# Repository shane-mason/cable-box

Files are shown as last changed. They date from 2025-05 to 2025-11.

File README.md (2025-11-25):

# cable-box
3d Printable Cable Box Model

The models were used to make a 3-d printed cable box replica to house a Raspberry Pi 5 for a cable simulation built using FieldStation42.

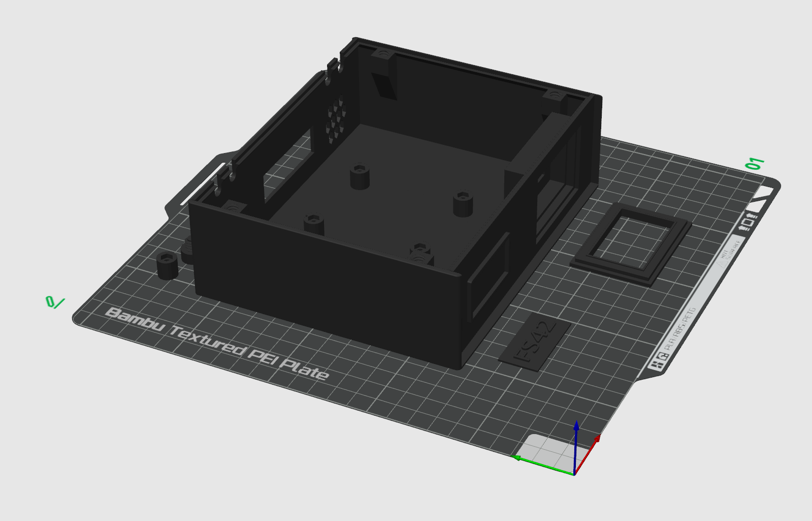
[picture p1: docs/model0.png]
A screenshot cable box model


To use the models, clone the repository and print both sets:

```
CableBox-main.stl - Contains the main box, trim pieces and foot screws.
CableBox-bottom.stl - Conains the bottom of the box.
```

## List of Materials Used
* [3x4 Matrix Keypad](https://www.adafruit.com/product/3845)
* [4 Digit 7 Segment TM1637 LED Display Board](https://www.amazon.com/dp/B0BFQNFX6D)
* [Raspberry Pi 5 - with active cooler](https://www.adafruit.com/product/5815)
* [F2F Jumper Wires](https://www.adafruit.com/product/1950)
* 6"+ Micro HDMI to HDMI Adapter (pigtail)
* Plexiglass (1/8th inch)
* 4 M2.5 screws and nuts
* 4 M2 screws and nuts
* Superglue

## Building the Box
The put it all together, follow the steps below. At the finish, you should have a box that looks like this:
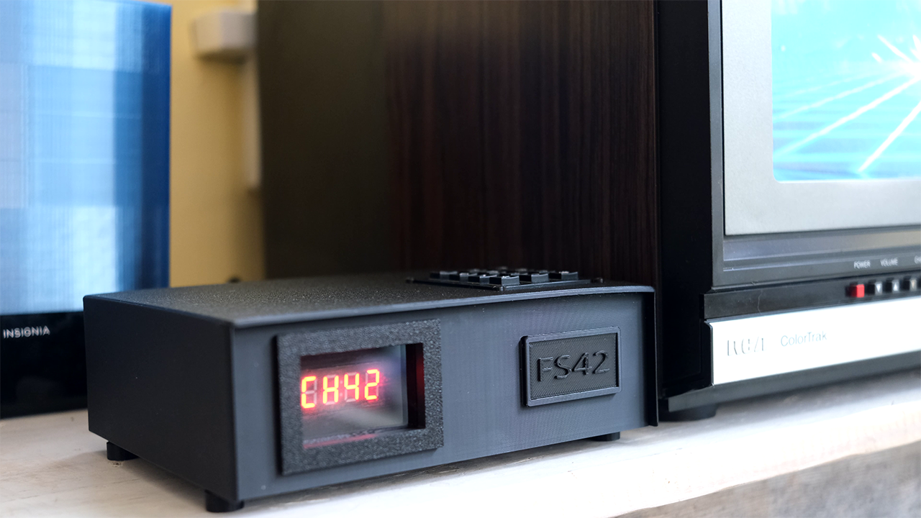
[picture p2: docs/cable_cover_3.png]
A cable box on a table with wired connecting components


### Step 1 - Printing
Print both models above. I used PLA with a .4 mm nozel on a textured plate - but ABS should work.

### Step 2 - Mounting the Pi
The printed model contains mounts for the raspberry pi 5 on the top of the box. There are cutouts in each mounting post for an M2.5 nut to fit into - secure it with superglue.
        
After the superglue is dried, just use M2.5 screws to secure it to the post.

Its important to use a pi with an active cooler - otherwise it will likely heat up and throttle perfomance. 

### Step 3 - Mount the Keypad
The keypad mounts using M2 screws and nuts in the corners of the cutout on the top of the box.

### Step 4 - Mount the LED Display
The display mounts in the cutout in the front of the box using superglue. The fit should be fairly tight, but it also works as long as it is glued to one of the two sides. There is room for improvement in this part of the design for sure.

Optional: cut plexiglass to SIZE and fit in front of the display.

Fit black trim piece over the display area.

### Step 5 Wire It Up!
In this step, you'll connect all the wires. Your setup should look like the picture below at the end of this step:

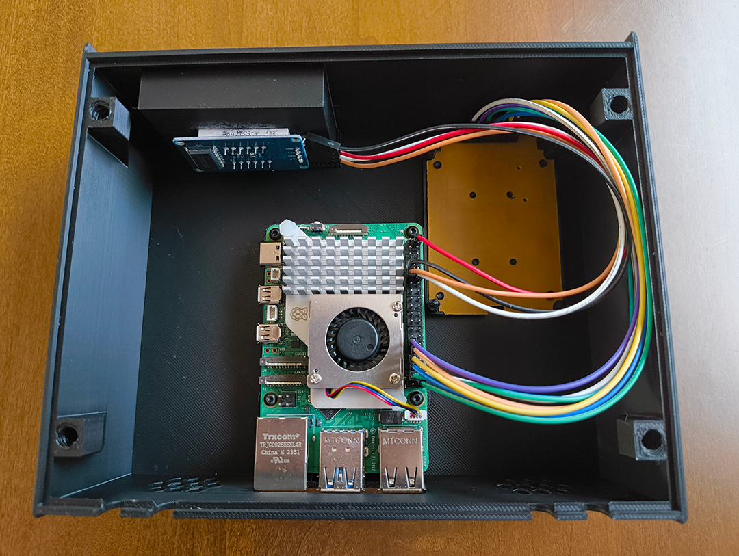
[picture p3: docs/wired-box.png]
A cable box on a table with wired connecting components


#### TM1637 LED Display Board

The following table shows the connections betwen the Rasberry Pi 5 and the TM1637 LED Display Board.

| Raspberry PI  |LED Display |
| --- | --- |
|A 5v |VCC |
|GND  |GND |
|GPIO17  |CLK |
|GPIO18  | DIO |

#### 3x4 Matrix Keypad

The following table shows the connections between the Raspberry Pi 5 and the 3x4 Matrix Keypad. For more information on the pinouts for this keypad and the Raspberry Pi 5, see [this Adafruit Learning Guide](https://learn.adafruit.com/matrix-keypad/overview).

| Raspberry PI  |Keypad |
| --- | --- |
|GPIO20|C2|
|GPIO05|R1|
|GPIO26|C1|
|GPIO19|R4|
|GPIO21|C3|
|GPIO13|R3|
|GPIO06|R2|

#### Fritzing Diagram

The following diagram shows an overview of the connections.

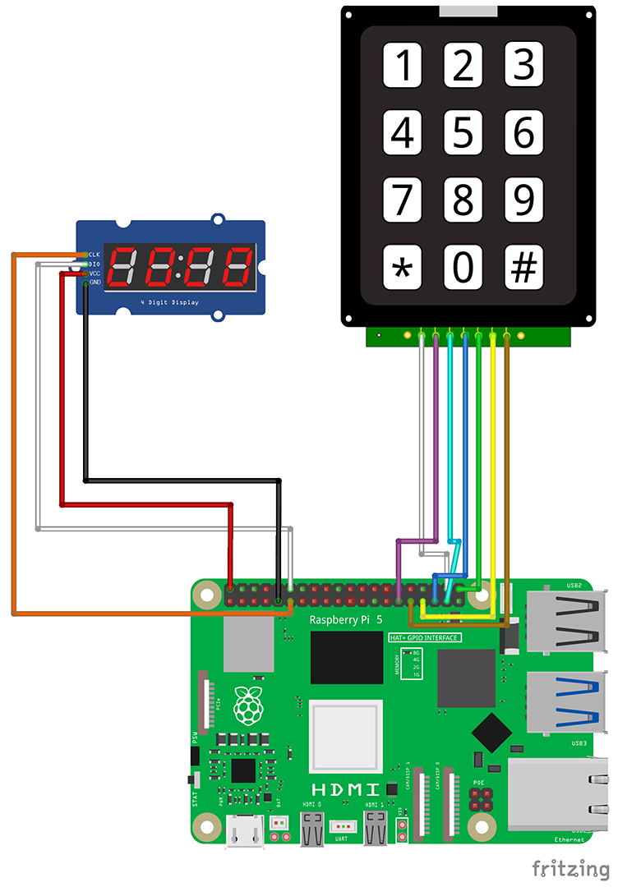
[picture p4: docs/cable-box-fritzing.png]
A connection diagram


Additional documentation with images is in-progress.

### Step 5: Connect Power & HDMI

In this step, just connect the micro-HDMI to HDMI pigtail to the Pi's micro-HDMI output and the power cable to the Pi's USB C connector and run them through the openings on the side closest to the connectors. You will probably want to use use something to prevent the cables from being pulled, so I use some thick copper wire. A think ziptie or some tape wil work also. When this step is completed, it should look like the picture below.

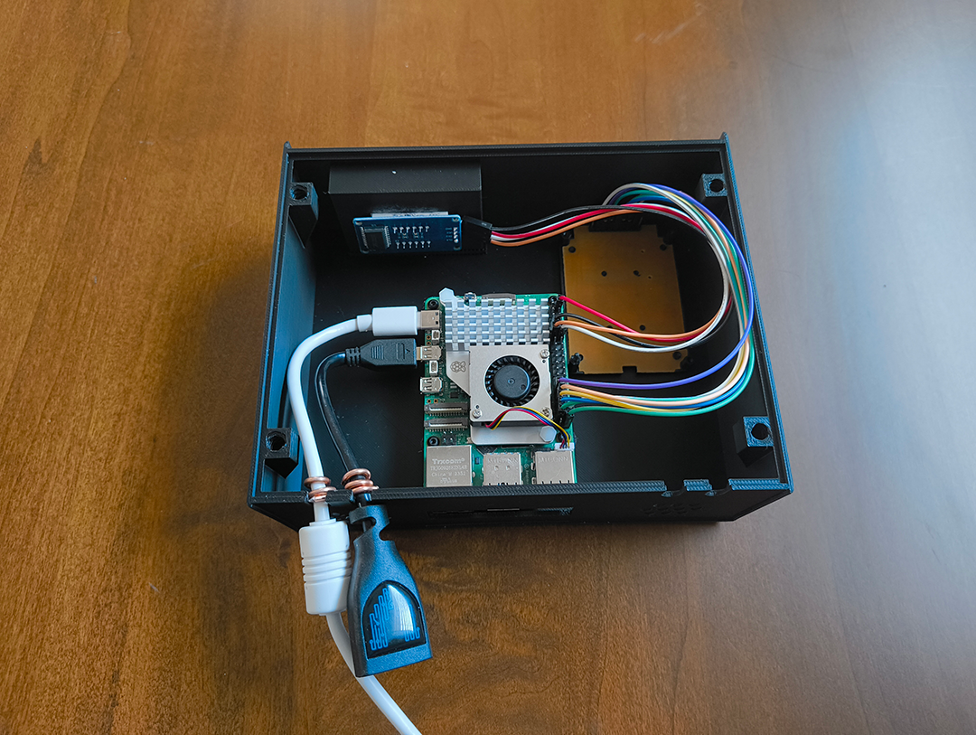
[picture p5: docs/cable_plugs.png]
Cable box with wires


### Step 6: Secure Bottom
Use the foot screws in the first print to secure the bottom piece from the second print.

## Setting Up the Software

To use the cable box script, you will need to install the python drivers for the LED display and matrix keypad. The script is located in the FieldStation42 repo at `fs42/pi/cable_box.py` ([link](https://github.com/shane-mason/FieldStation42/blob/main/fs42/pi/cable_box.py)).

### Install Keypad Drivers

For the matrix keypad, you you first need to install Adafruit Blinka libraries. 
- [Follow this guide to install CircuitPython via Blinka](https://learn.adafruit.com/circuitpython-on-raspberrypi-linux/installing-circuitpython-on-raspberry-pi)

Next, install the matrix keypad driver using pip3 (after you activate your virtual env)

```
source env/bin/activate
pip3 install adafruit-circuitpython-matrixkeypad
```

### Install LED Drivers

Use pip to install tm1637 LED drivers

```
source env/bin/activate
pip3 install raspberrypi-tm1637
```

### 

If you get an error along the lines of:
```
RuntimeError: Cannot determine SOC peripheral base address
```
Run the following:

```
sudo apt remove python3-rpi.gpio
pip3 install rpi-lgpio
```
### Starting the Script on Startup

For ideas about how to use this at startup, see [this wiki page](https://github.com/shane-mason/FieldStation42/wiki/Autostart-on-Rasberry-Pi).

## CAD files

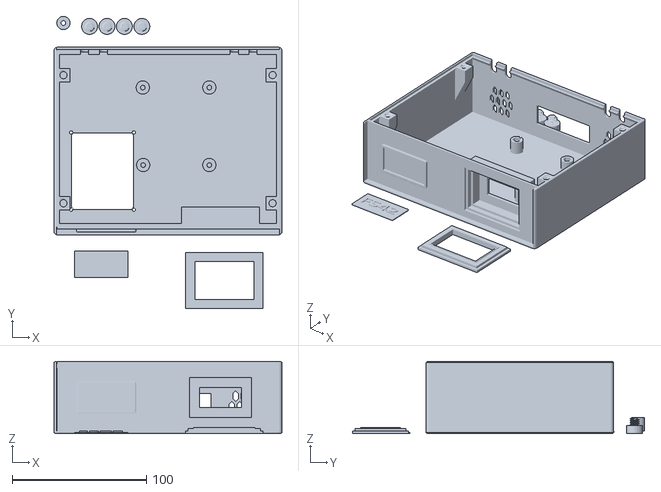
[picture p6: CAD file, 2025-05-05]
models/CableBox-main.stl
170.0 x 218.0 x 54.0

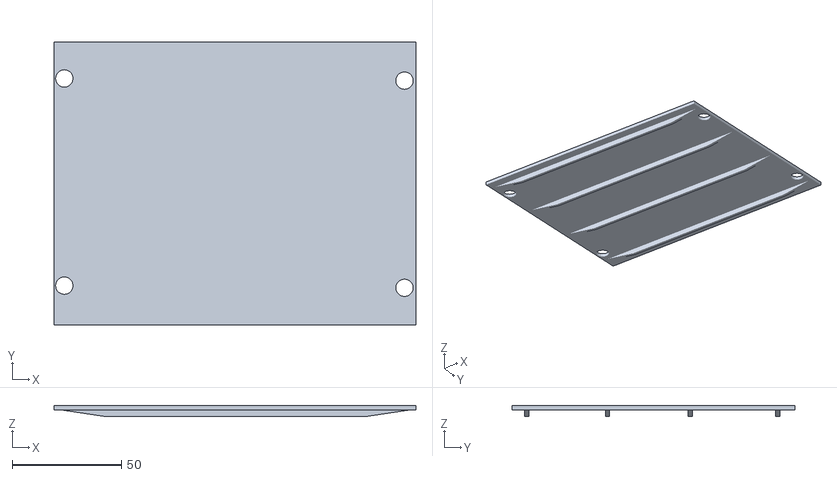
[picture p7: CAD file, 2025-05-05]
models/CableBox-bottom.stl
166.0 x 130.0 x 5.00

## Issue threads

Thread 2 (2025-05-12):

model needs supports or a tweak

ddrfr33k, 2025-05-12:
Hi there! I noticed something with the upper half of the case. The housing that holds the LED has an overhang that requires supports inside the case. See below:

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

Because the supports don't touch the build plate, you have to generate supports everywhere, which puts a bunch of schmutz on the inside of the screw holes that attach to the bottom plate. You might want to consider making that block one solid piece, so you don't need supports.

shane-mason, 2025-05-16:
Good callout - I had just painted supports there, so it didn't get in the screw holes. I'll just make it solid.

pablomcnally, 2025-05-16:
Just printed my box! Looks great! Looking forward to getting a Pi5 in there when I get back from vacation

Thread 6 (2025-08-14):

JLPCB resin printing issue

Tom-Neverwinter, 2025-08-14:
my printer has not been cooperating with the large flat area of the base so JLPCB it is.

however sadly the box has very thin walls for resin printing:

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

shane-mason, 2025-08-15:
Hey there - let's go through these:

> 1,the wall thickness of those indicated red area is too thin, which has high risks of loss, deformation, crack, or damage during the printing process.

The red areas appear to be where the foot-screws go in? What is the correct thickness? I am not sure I know how to increase the thickness and still have it work. This was the first time I made scews and threaded holes.

> 2, please refer to the green areas, there are multiple shells which cannot be merged automatically. Due to each file could only support 1 part (shell) for printing, could you please kindly merge the shells/parts by yourself and upload the file again? To save time, we will activate the 'replace file' button for you

Also, not entirely sure what this means? Is that rail just not 'connected' to the rest well enough?

Tom-Neverwinter, 2025-08-17:
JLCPCB is warning you about two common 3D printing issues. First, the walls around your screw holes are too thin; for resin printing you’ll want at least 1 mm minimum wall thickness, but for screw bosses it’s best to leave about 2 mm of solid material around the hole so it doesn’t crack. If you modeled threads directly, it may be easier to just leave a pilot hole and cut threads afterward or use threaded inserts. Second, the “multiple shells” note means your STL file has more than one separate solid body (for example, if the rail or a feature isn’t truly fused with the main part), and the printer only accepts one merged body per file. To fix that, just union or combine all your bodies in CAD or mesh software so the part exports as a single watertight solid. That should get your design past their checks.

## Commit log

2025-05-05 Base models
    [CableBox-bottom.stl, CableBox-main.stl]
2026-10-25 Add power button
